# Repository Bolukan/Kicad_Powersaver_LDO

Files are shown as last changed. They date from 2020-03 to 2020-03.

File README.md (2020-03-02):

# Kicad_Powersaver_LDO
Latching Power Circuit in Kicad

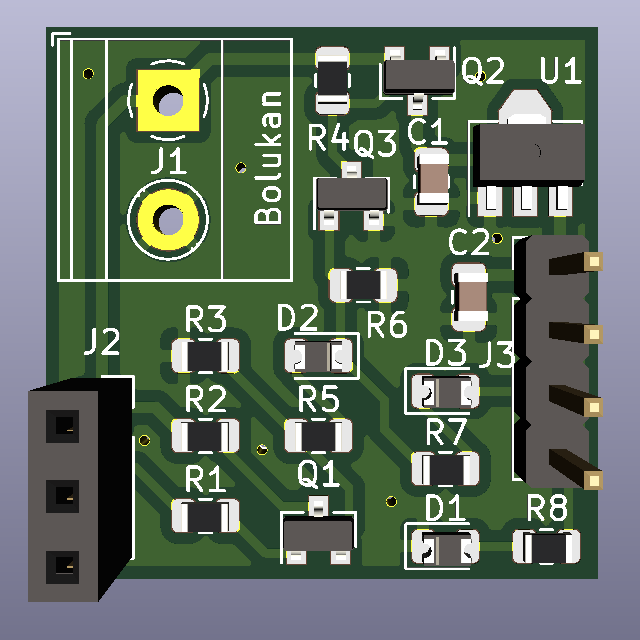
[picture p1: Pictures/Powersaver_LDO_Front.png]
Front of PCB

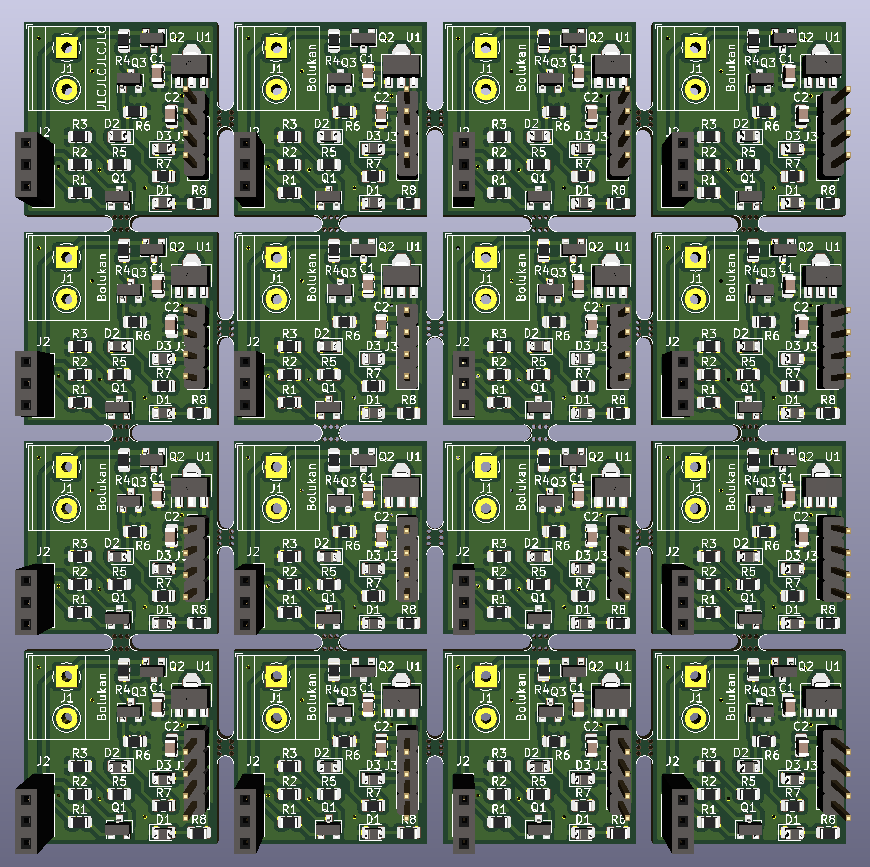
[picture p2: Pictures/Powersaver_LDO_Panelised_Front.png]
Front of panelised PCB

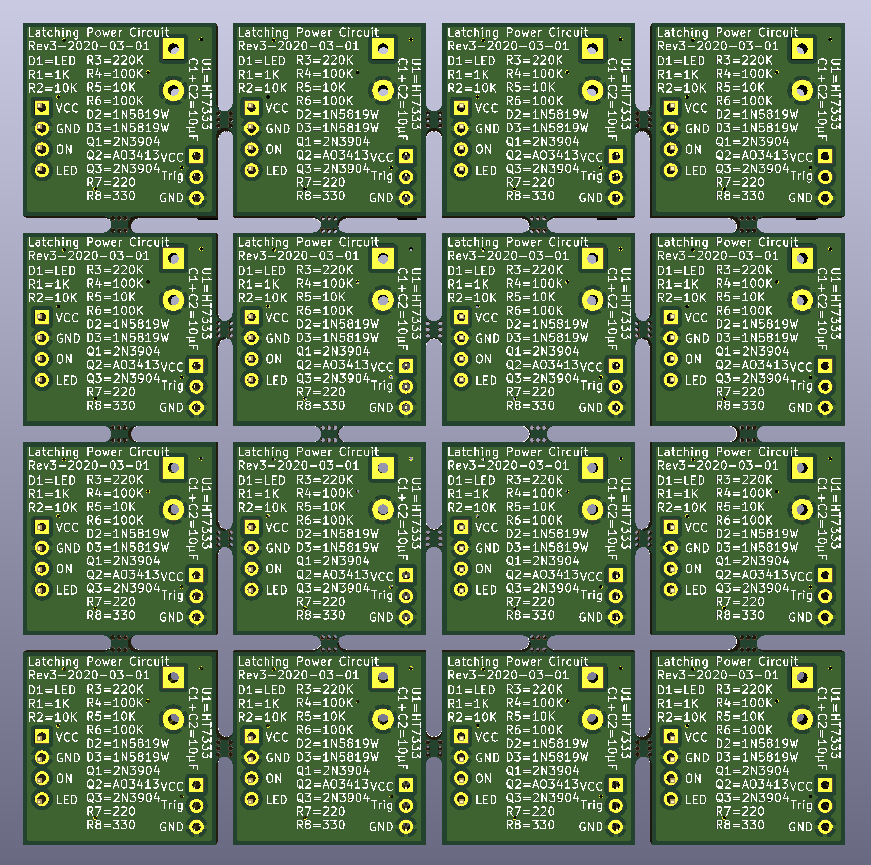
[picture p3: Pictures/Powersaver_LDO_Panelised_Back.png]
Back of panelised PCB


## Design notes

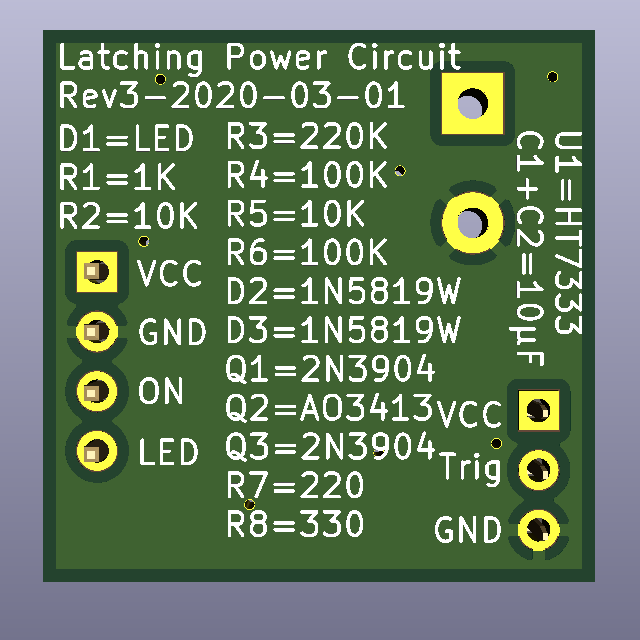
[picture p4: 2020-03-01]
Pictures/Powersaver_LDO_Back.png

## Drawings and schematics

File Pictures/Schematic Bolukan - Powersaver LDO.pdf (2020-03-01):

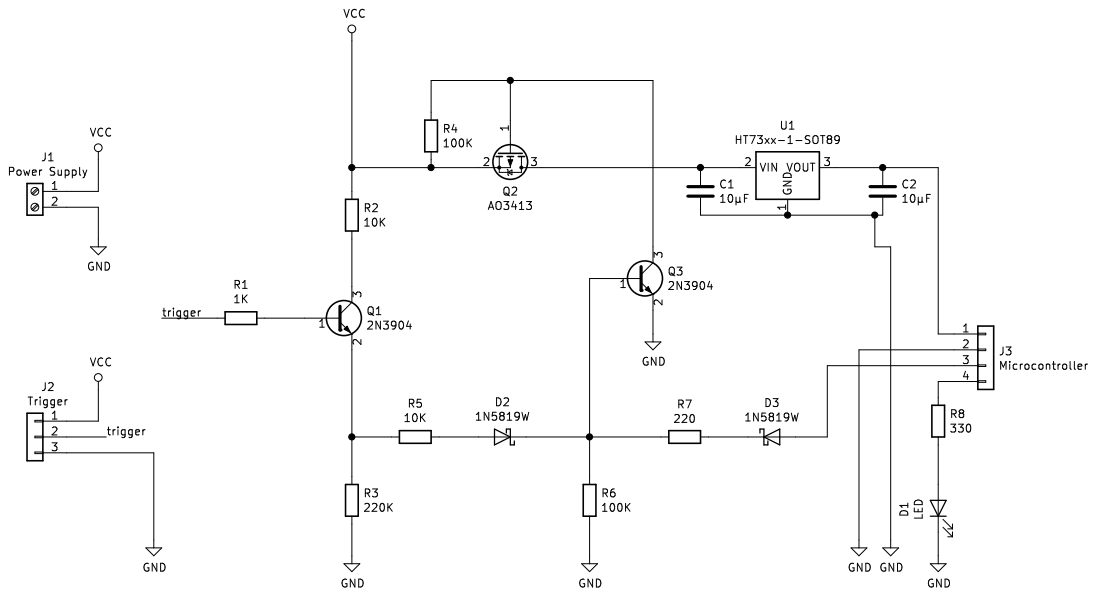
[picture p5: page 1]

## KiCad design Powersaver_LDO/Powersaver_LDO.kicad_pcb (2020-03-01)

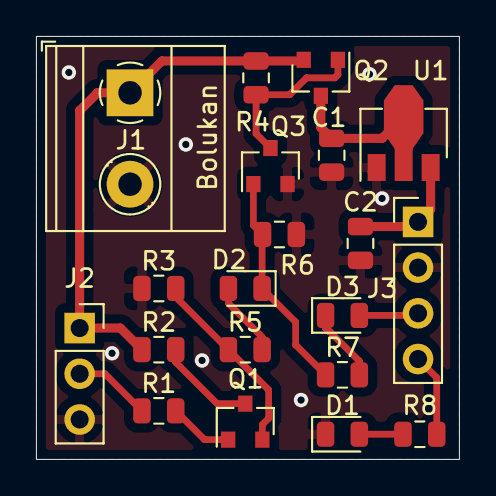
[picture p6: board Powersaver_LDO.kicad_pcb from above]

Board: 2 copper layers, 23.5 x 23.5 mm, 20 parts (0 on the bottom side), 15 nets.

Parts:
C1, C2: 10µF; C_0805_2012Metric
D1: LED; D_0805_2012Metric
D2, D3: 1N5819W; D_0805_2012Metric
J1: Power Supply; TerminalBlock_Phoenix_MKDS-1,5-2-5.08_1x02_P5.08mm_Horizont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
J2: Trigger; PinSocket_1x03_P2.54mm_Vertical
J3: Microcontroller; PinHeader_1x04_P2.54mm_Vertical
Q1, Q3: 2N3904; SOT-23
Q2: AO3413; SOT-23
R1: 1K; R_0805_2012Metric
R2, R5: 10K; R_0805_2012Metric
R3: 220K; R_0805_2012Metric
R4, R6: 100K; R_0805_2012Metric
R7: 220; R_0805_2012Metric
R8: 330; R_0805_2012Metric
U1: HT73xx-1-SOT89; SOT-89-3

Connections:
/trigger: J2.2, R1.1
GND: C1.2, C2.2, D1.1, J1.2, J2.3, J3.2, Q3.2, R3.2, R6.2, U1.1
unnamed: C1.1, Q2.3, U1.2
unnamed: C2.1, J3.1, U1.3
unnamed: D1.2, R8.2
unnamed: D2.1, Q3.1, R6.1, R7.2
unnamed: D2.2, R5.2
unnamed: D3.1, R7.1
unnamed: D3.2, J3.3
unnamed: J3.4, R8.1
unnamed: Q1.1, R1.2
unnamed: Q1.2, R3.1, R5.1
unnamed: Q1.3, R2.2
unnamed: Q2.1, Q3.3, R4.1
VCC: J1.1, J2.1, Q2.2, R2.1, R4.2

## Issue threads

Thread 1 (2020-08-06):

Will 10K pulldown on trigger improve circuit?

Bolukan, 2020-08-06:
Will a 10K pulldown resistor at the trigger improve the performance?
I ran a simulation [Multisim Power Saving Latching Circuit](https://www.multisim.com/content/5EigTzk8oTnUGG7HghrEpb/power-saving-latching-circuit/open/) which confirms the advantages.

The voltage at the base will be drained with the pulldown from 25% of VCC to <1mV.
The power consumption lowers from 4 µA to 0,04 µA.

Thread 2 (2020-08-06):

Why is R6 220 Ohm?

Bolukan, 2020-08-06:
According to the [schematic](https://github.com/Bolukan/Kicad_Powersaver_LDO/blob/master/Pictures/Schematic%20Bolukan%20-%20Powersaver%20LDO.pdf) a 220 ohm resistor (and a diode) is connected to the MCU pin.

The expected power consumption will be approx. 10mA (3,3V - 0,7 VF) / 220 Ohm.
For the MOSFET to function a voltage of 20mV at the gate is more than sufficient.

If R6 is 2,2K Ohm the power is 1mA and the MOSFET gate is still < 20mV.
If R6 is 22K Ohm the power is 0,1mA and the MOSFET gate is still 23mV.
If R6 is >100K Ohm in combination of R8 the remaining amperes becomes too little.

So it is an easy gain to lower the power consumption and safeguard the pin current by raising it to 2,2K Ohm.

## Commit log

2020-03-02 Add Panelised, including Gerber
    [Powersaver_LDO.kicad_pcb, Powersaver_LDO.sch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]
2020-03-02 Corrected to Rev3 2020-03-01
    [Powersavers-B_Cu.gbr, Powersavers-B_Mask.gbr, Powersavers-B_Paste.gbr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]
2020-03-02 Pictures of panelised gerber
